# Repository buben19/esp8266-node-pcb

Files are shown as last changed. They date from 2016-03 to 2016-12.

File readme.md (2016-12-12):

# ESP8266 Node PCB

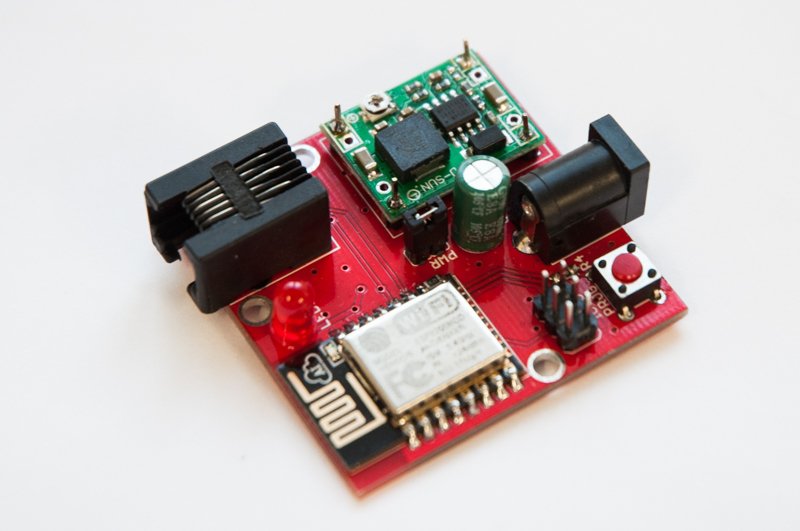
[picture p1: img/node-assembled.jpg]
Assembled node


Design of esp8266 board PCB. This should be base design for esp8266 IoT devices.

## Features

 - Powered by mini DC-DC power supply module ([LM2596](http://www.ti.com/lit/ds/symlink/lm2596.pdf) chip).
 - 5.5 mm center positive jack.
 - On-board programming connector.
 - Programming push button.
 - Jumper for enabling power supply module.
 - RJ-11 connector for connecting various sensors.
 - Notification LED.
 - Intended to be manufactured by [dirtypcbs.com](http://dirtypcbs.com/).
 - AVR like ISP header for in circuit programming.

## Images

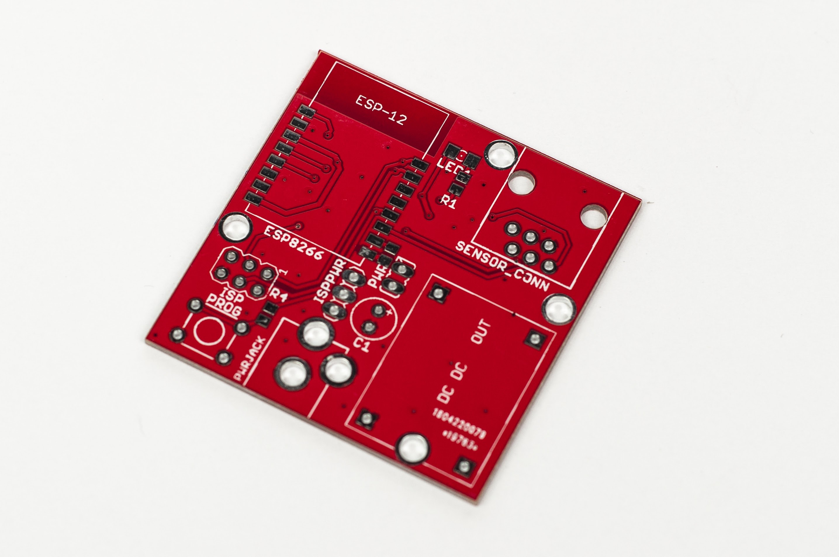
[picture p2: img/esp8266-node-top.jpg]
Top view


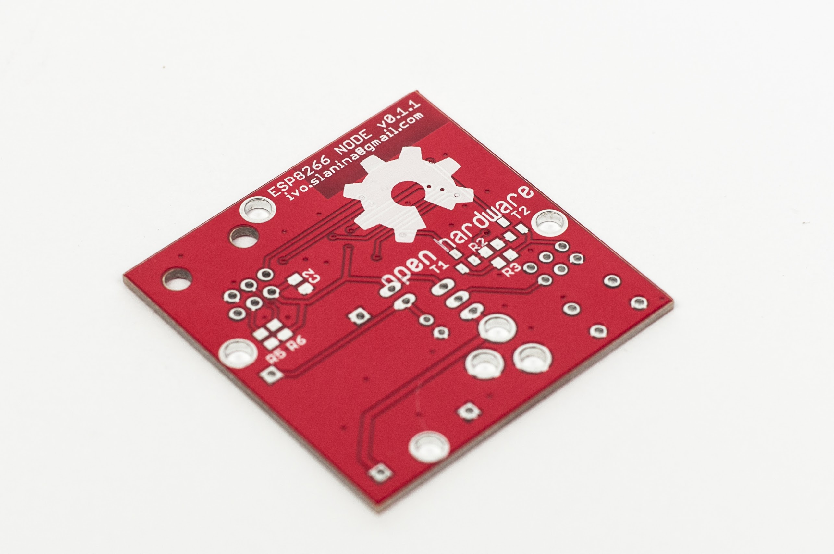
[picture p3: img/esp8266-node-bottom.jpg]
Bottom view


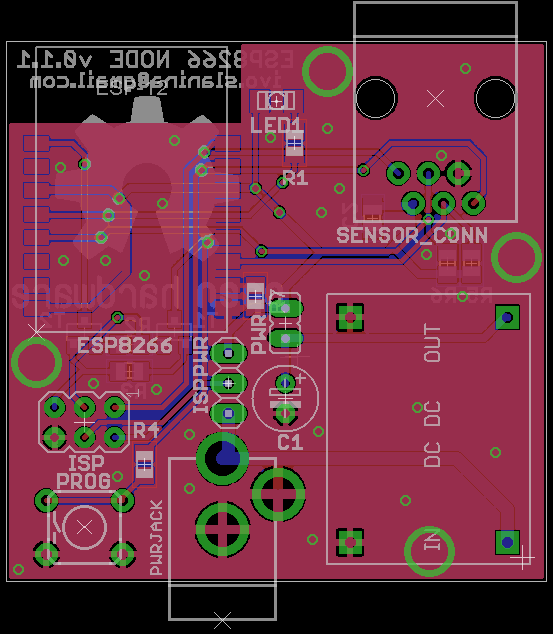
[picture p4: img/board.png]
Board design Node board design


## Get board

You can order PCB on this [link](http://dirtypcbs.com/store/designer/details/9988/941/esp8266-pcb-v0-1-2-zip).

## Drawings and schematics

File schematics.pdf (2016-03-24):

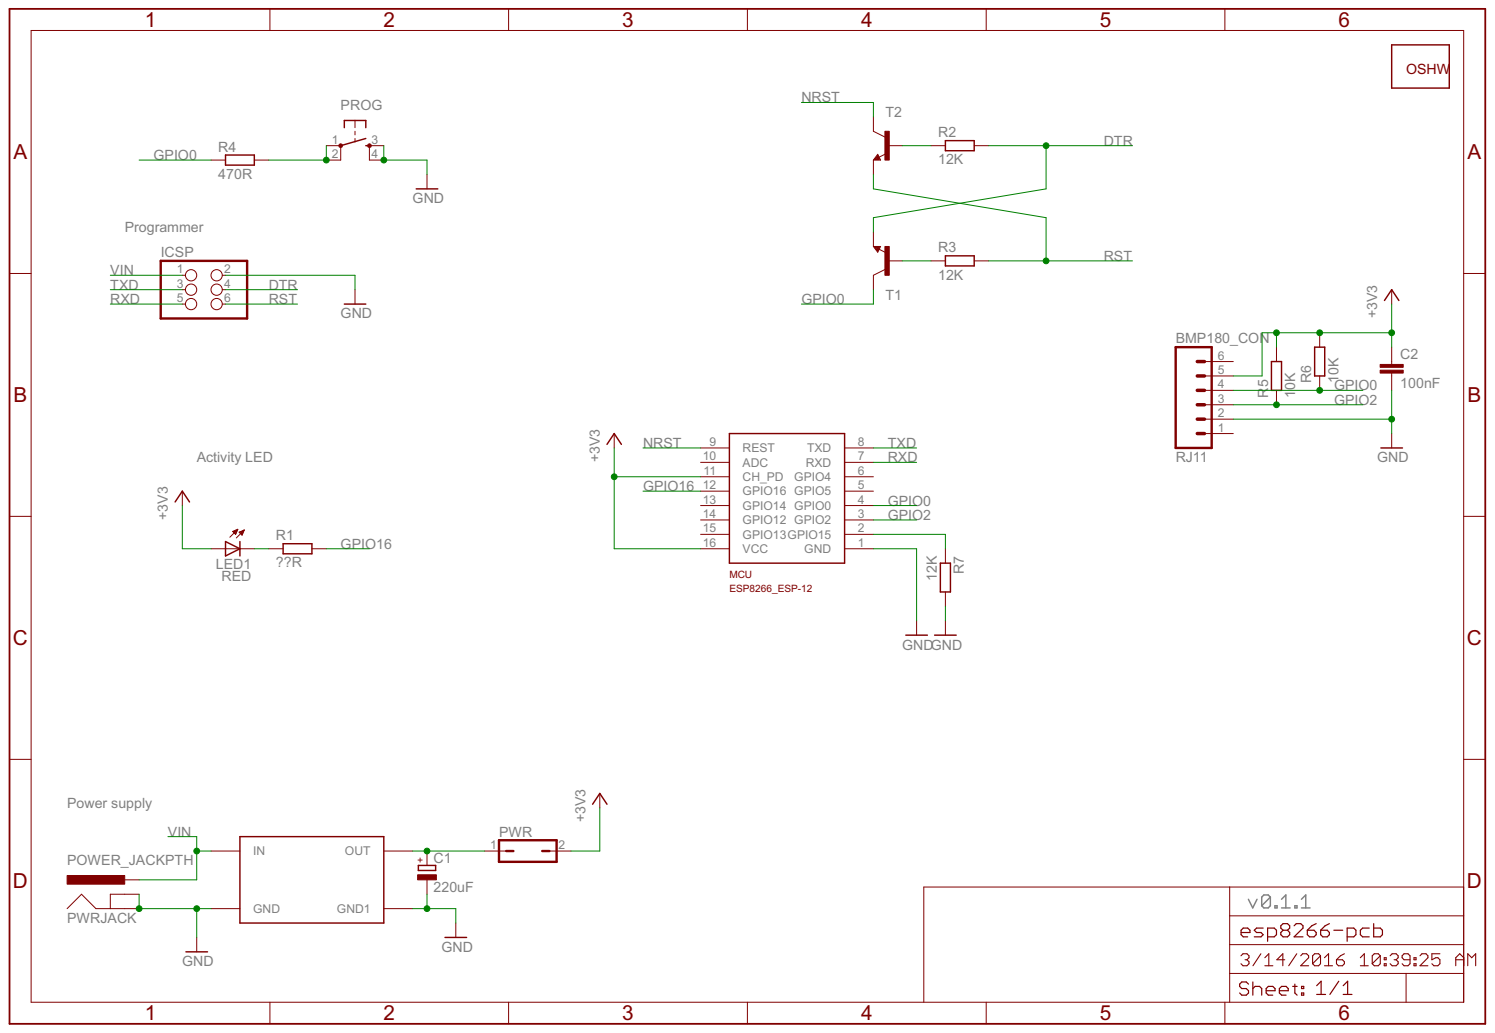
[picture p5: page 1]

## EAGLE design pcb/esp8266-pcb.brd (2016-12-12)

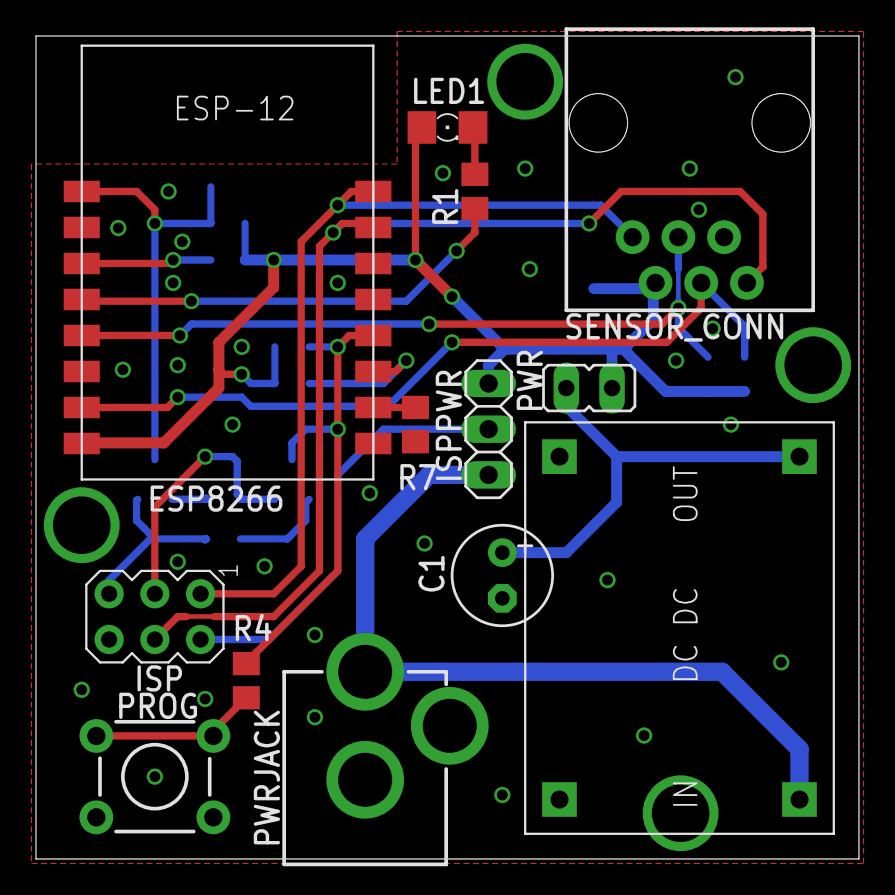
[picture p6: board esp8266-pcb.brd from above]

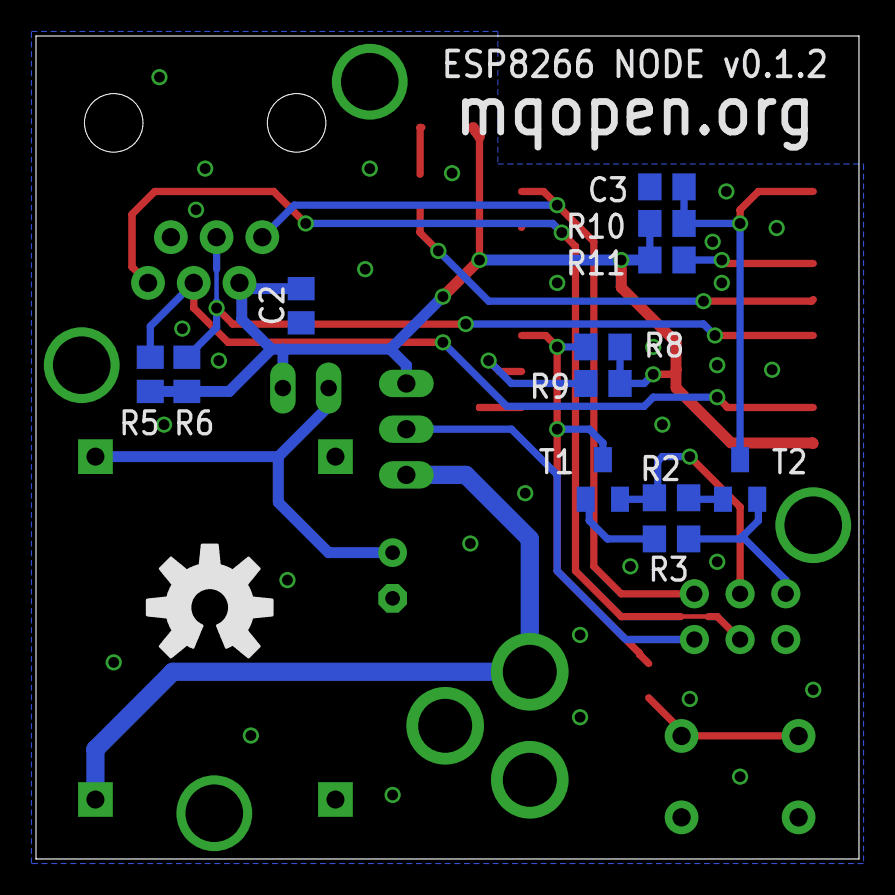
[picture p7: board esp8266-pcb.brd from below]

Board: 2 copper layers, 45.7 x 45.7 mm, 26 parts (13 on the bottom side), 21 nets.

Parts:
C1: 220uF; E2,5-6
C2, C3: 100nF; C0805
ESP8266: ESP8266_ESP-12; ESP8266-ESP12
ISP: AVRISP-6; AVRISP
ISPPWR: 1X03
LED1: RED; 1206
PROG: TACTILE-PTH
PWR: JP1
PWRJACK: POWER_JACKPTH; POWER_JACK_PTH
R1: 82R; R0805
R2, R3, R7, R8, R9, R10, R11: 12K; R0805
R4: 470R; R0805
R5, R6: 10K; R0805
SENSOR_CONN: RJ11; RJ11-6
T1, T2: SOT23-BEC
U$1: OSHW-LOGOL; OSHW-LOGO-L
U$2: DC-DC-SMALL; DC-DC

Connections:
+3V3: C2.2, ESP8266.16, ISPPWR.1, LED1.A, PWR.2, R5.2, R6.2, R8.2, R9.2, R10.2, R11.2, SENSOR_CONN.5
DTR: ISP.3, R2.2, T1.E
EN: ESP8266.11, R11.1
GND: C1.-, C2.1, C3.1, ESP8266.1, ISP.6, PROG.3, PROG.4, PWRJACK.GND, PWRJACK.GNDBREAK, R7.2, SENSOR_CONN.2, U$2.P$3, U$2.P$4
GPIO0: ESP8266.4, R4.1, R8.1, T1.C
GPIO2: ESP8266.3, R9.1
GPIO13: ESP8266.15, R5.1, SENSOR_CONN.3
GPIO14: ESP8266.13, R6.1, SENSOR_CONN.4
GPIO16: ESP8266.12, R1.2
unnamed: LED1.C, R1.1
unnamed: C1.+, PWR.1, U$2.P$2
unnamed: R2.1, T2.B
unnamed: PROG.1, PROG.2, R4.2
unnamed: ESP8266.2, R7.1
unnamed: ISP.2, ISPPWR.2
unnamed: R3.1, T1.B
NRST: C3.2, ESP8266.9, R10.1, T2.C
RST: ISP.5, R3.2, T2.E
RXD: ESP8266.7, ISP.4, SENSOR_CONN.1
TXD: ESP8266.8, ISP.1, SENSOR_CONN.6
VIN: ISPPWR.3, PWRJACK.PWR, U$2.P$1

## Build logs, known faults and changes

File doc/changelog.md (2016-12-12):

# ESP8266 Node changelog

## v0.1

 - First board design. Designed to have one [bmp180](https://www.adafruit.com/products/1603) sensor connected to RJ-11 connector.
 - Intended to be manufactured by [dirtypcbs.com](http://dirtypcbs.com/).
 - Powered by mini DC-DC power supply module ([LM2596](http://www.ti.com/lit/ds/symlink/lm2596.pdf) chip).
 - 5.5 mm center positive jack.
 - On-board programming connector.
 - Programming push button.
 - Jumper for enabling power supply module.
 - THT notification LED.

## v0.1.1

 - GPIO15 grounded with 12K resistor.
 - Board label changed to "ESP8266 NODE".
 - THT notification LED replaced with SMD 1206 package.
 - RJ-11 label changed to "SENSOR_CONN"
 - Changed pin order on ISP header. Now it chould be similiar to AVR ISP header.
 - Added ESP8266 RX and TX pins to unused RJ-11 pins (1 and 6).
 - GPIO0 is used only for entering programming mode. Not used in RJ-11 connector.
 - RJ-11 is connected to GPIO2 and GPIO14 pins.
 - ISP voltage pin is connected to 3-pin jumper. User can choose to connect it to 3V3, VIN or disconnect it.

## v0.1.2

 - Added 12K pull-up resistor to GPIO0 and GPIO2 pins.
 - Rearranged some components.
 - RJ-11 is connected to GPIO13 and GPIO14 pins.
 - Added "mqopen.org" label.
 - Removed personal email address.
 - CH_PD pulled up with 12K resistor.
 - NRST pulled up with 12K resistor and added 100nF capacitor.
 - Smaller openhw logo.

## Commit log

2015-11-30 initial commit.
    [esp8266-pcb.sch]
2016-02-01 Project refactoring.
    [esp8266-pcb.sch]
2016-02-04 Removed one RJ-11 port. Added board design.
    [esp8266-pcb.brd, esp8266-pcb.sch]
2016-02-04 Added mount holes.
    [esp8266-pcb.brd, esp8266-pcb.sch]
2016-02-04 Rearanged bNames and tNames.
    [esp8266-pcb.brd, esp8266-pcb.sch]
2016-02-04 Added vias.
    [esp8266-pcb.brd]
2016-02-06 Added power enable jumper.
    [esp8266-pcb.brd, esp8266-pcb.sch]
2016-02-06 Changed some routing.Changed some routing.
    [esp8266-pcb.brd, esp8266-pcb.sch]
2016-02-07 Fixed typo at board description. Rearranged labels.
    [esp8266-pcb.brd]
2016-02-07 Added OpenHW logo.
    [esp8266-pcb.brd, esp8266-pcb.sch]
2016-02-08 Minor board and schematic refactoring.
    [esp8266-pcb.brd, esp8266-pcb.sch]
2016-02-08 Removed unused nets.
    [esp8266-pcb.brd, esp8266-pcb.sch]
2016-02-09 Minor board refactoring.
    [esp8266-pcb.brd, esp8266-pcb.sch]
2016-03-13 GPIO15 grounded with 12K resistor.
    [esp8266-pcb.brd, esp8266-pcb.sch]
2016-03-14 Changed board label.
    [esp8266-pcb.brd]
2016-03-14 Notofication LED replaced with 1206 package.
    [esp8266-pcb.brd, esp8266-pcb.sch]
2016-03-14 Component rerouting.
    [esp8266-pcb.brd]
2016-03-24 Added schematic pdf and board image.
2016-04-20 Updated schematics.
    Changed sensor connection pins.
    Changed pin order on ICSP header.
    Added RX and TX ping to unused RJ-11 pins.
    [esp8266-pcb.brd, esp8266-pcb.sch]
2016-04-20 Added jumper to ICSP voltage pin.
    [esp8266-pcb.brd, esp8266-pcb.sch]
2016-04-20 Board routing.
    [esp8266-pcb.brd, esp8266-pcb.sch]
2016-04-20 Updated ISP header.
    [esp8266-pcb.brd, esp8266-pcb.sch]
2016-04-20 Updated board image.
2016-12-12 Added new board designs.
    [esp8266-pcb.brd, esp8266-pcb.sch]
2016-12-12 Added gerber files.
    [esp8266-pcb.GBL, esp8266-pcb.GBO, esp8266-pcb.GBS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]

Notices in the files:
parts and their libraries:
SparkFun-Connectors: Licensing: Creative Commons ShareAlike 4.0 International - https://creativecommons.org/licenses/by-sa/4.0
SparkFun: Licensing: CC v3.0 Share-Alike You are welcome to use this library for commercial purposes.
